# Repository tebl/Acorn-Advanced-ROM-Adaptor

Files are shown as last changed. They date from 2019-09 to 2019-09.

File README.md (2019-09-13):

# Acorn Advanced ROM Adaptor

Recently picked up something called an Advanced ROM MKII Adaptor, a 16K sideways ROM- RAM Adaptor for The Acorn Electron by Advanced Computer Products. The one I have looks like the one below, unfortunately it was had no sockets so both all the ROMs were soldered in and the jumpers used to select the type of chips installed (8K SRAM, 8K ROM or 16K ROM) were nowhere to be seen so not the most exciting piece of kit in my collection. So I decided to recreate the board instead of tearing it down and hacking it to pieces.

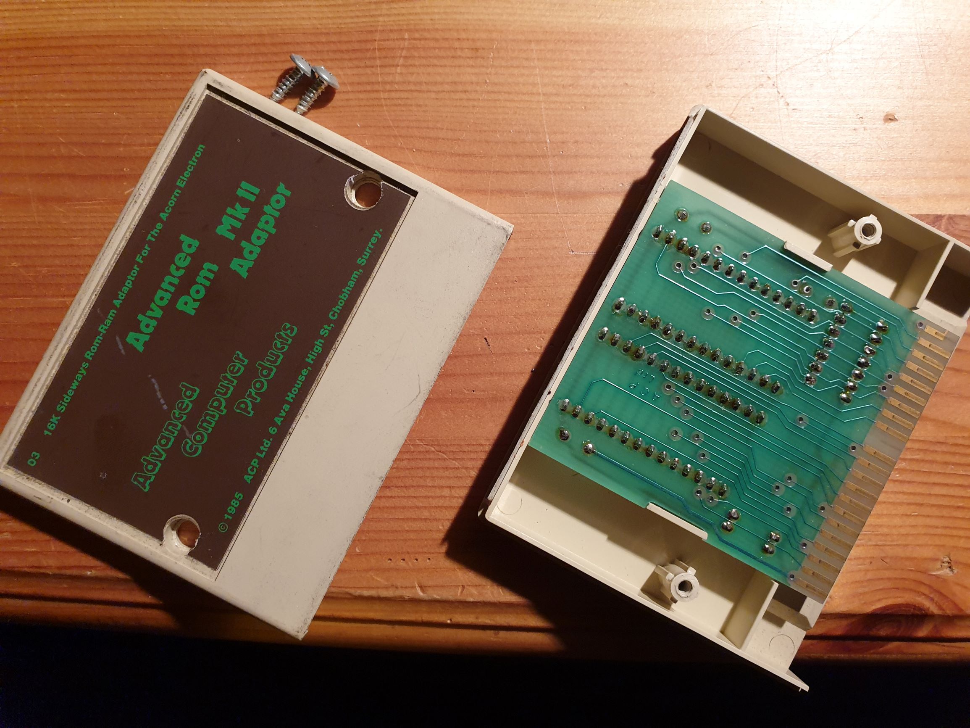
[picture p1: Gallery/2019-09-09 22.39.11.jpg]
MKII ROM Adaptor


The original release of the product had a MKI which only sported a single EPROM, the MKII as already described has the capacity for two chips with the aid of a small piece of added logic. I started by tracing out where every connection went on the MKII, adding up the details into a [schematic](https://github.com/tebl/Acorn-Advanced-ROM-Adaptor/raw/master/MK2%20Original/export/MK2%20Original.pdf) that can be found as part of the project found in*MK2 Original*. I've included them for any that would like to have that kind of information available when attempting to repair a similar cartridge.

Finally I wanted one that I could mess around with, so with the schematic in mind I started drawing out a *MKIII Redux* version of it instead. The differences here is that I've replaced the 27128/27C128, that are a pain to track down and pay for, with the plentiful 27C512 chips instead. This bumps the capacity of the cartridge from 2x16K to 8x16K, addressing is kept the same - the remaining slots are available by changing the jumper settings. 

# Versions
For added details, see following project pages:
- [MKII Original](https://github.com/tebl/Acorn-Advanced-ROM-Adaptor/tree/master/MK2%20Original)
- [MKIII Redux](https://github.com/tebl/Acorn-Advanced-ROM-Adaptor/tree/master/MK3%20Redux)

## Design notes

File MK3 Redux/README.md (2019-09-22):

# Acorn Advanced ROM MKIII Redux

**UNTESTED**

Recently picked up something called an Advanced ROM MKII Adaptor, a 16K sideways ROM- RAM Adaptor for The Acorn Electron by Advanced Computer Products.  I've added a schematic for the MKII as part as the [MKII Original](https://github.com/tebl/Acorn-Advanced-ROM-Adaptor/tree/master/MK2%20Original), this is the *MKIII Redux* and as the name implies it is my attempt to create a cartridge that I can mess around with - without tearing down and hacking up 30 year old irreplaceable hardware.

The differences from the original design is that I've replaced the 27128/27C128, that are a pain to track down and pay for, with the plentiful 27C512. This bumps the capacity of the cartridge from 2x16K to 8x16K though addressing is kept the same, the remaining slots are available by changing the jumper settings with the computer is unplugged. I could have gone for chips that are even larger in capacity, but I wanted something that is easy enough for anyone with a soldering iron to fix up for themselves and there really aren't all that much ROM-based software available so even with the limited 8 slots you'll still fit in most of the desirable titles anyway. Smaller EPROMs such as the 27C64 or 27C256 can still be used, just keep the A14/15 lines unjumpered.

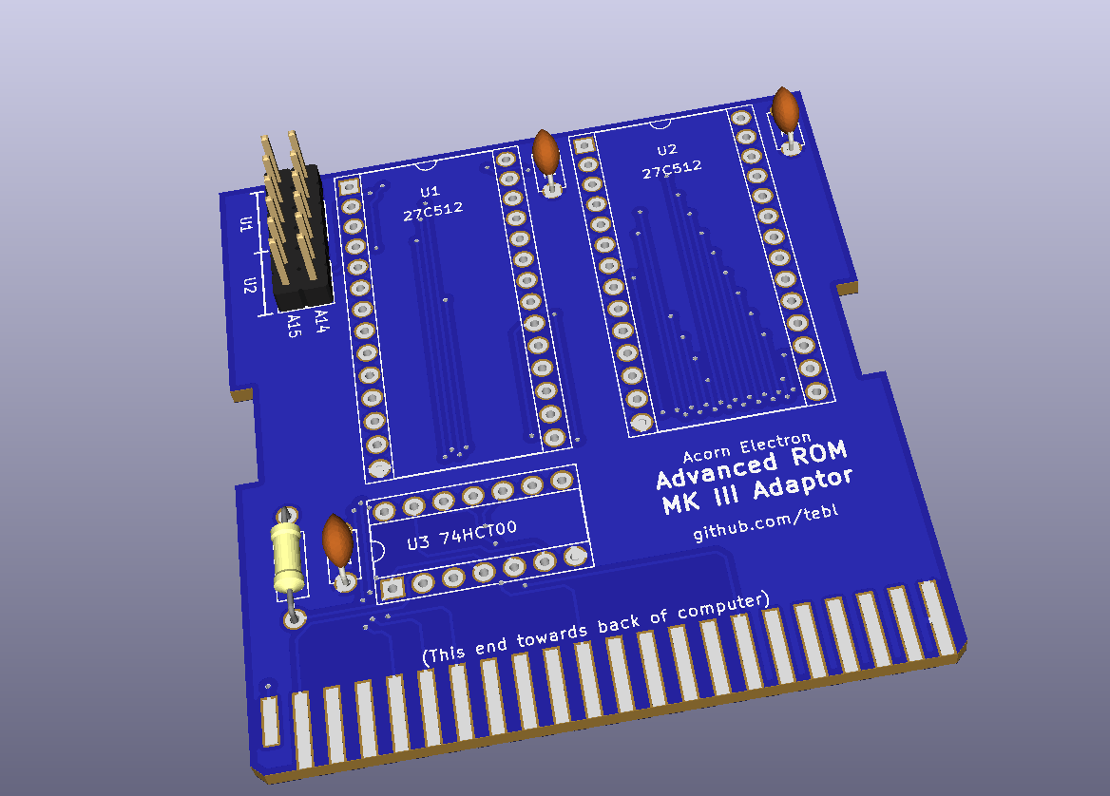
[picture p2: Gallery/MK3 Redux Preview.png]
MKIII Redux PCB Preview


# Schematic
The supplied KiCad files should be sufficient as both a schematic and as a  starting point for ordering PCBs (basically you could just zip the contents of the export folder and upload that on a fabrication site), the schematic is also available in [PDF-format](https://github.com/tebl/Acorn-Advanced-ROM-Adaptor/raw/master/MK3%20Redux/export/MK3%20Redux.pdf) and this is what you'll need to print and work your way through this things don't work as expected after assembly.

# BOM
Most parts should be easy to get a hold of from your favourite local electronic component shop, but given that I don't have access to such shops where I live so everything was based on whatever I could get cheapest from ebay/AliExpress (free shipping, plan on usually waiting 3-4 weeks though). The list below should be everything you'll need in addition to a workable soldering iron and some 60/40 soldering tin. Other tools needed for this project is an EPROM-ereaser as well as an EPROM-programmer for the two ICs (I use MiniPro TL866 for both).

Some vendors will have the same ICs in different form factors, the ones you want will often be specified as being in the form of a DIP/PDIP package. Usually you'll want sockets for each of the ICs as well, a bag of assorted sockets should be easily available without setting you back more than a couple bucks. With the sockets in place, you don't need to dread having to remove an IC later, this leads to easier fault finding and you can even "borrow" them for other projects later! For the pin headers, you probably won't find the exact pin count so just buy the longer versions and snip off the parts you don't need.

| Reference | Item | Count |
| --- | --- | ----- |
| PCB | Fabricate using Gerber files | 1 |
| C1-C3 | 100nF ceramic capacitor | 3 |
| R1 | 10k ohm resistor | 1 |
| U1,U2 | 27C512 DIP-28 | 2 |
| U3 | 74HCT00 DIP-16 | 1 |
| | Male 2x40-pin header (break to size)  | 1 |

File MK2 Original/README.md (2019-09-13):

# Acorn Advanced ROM MKII Original

Recently picked up something called an Advanced ROM MKII Adaptor, a 16K sideways ROM- RAM Adaptor for The Acorn Electron by Advanced Computer Products. The one I have looks like the one below, unfortunately it was had no sockets so both all the ROMs were soldered in and the jumpers used to select the type of chips installed (8K SRAM, 8K ROM or 16K ROM) were nowhere to be seen so not the most exciting piece of kit in my collection. So I decided to redraw the [schematic](https://github.com/tebl/Acorn-Advanced-ROM-Adaptor/raw/master/MK2%20Original/export/MK2%20Original.pdf) for the board, which explains this section of the project, instead of hacking up the cartridge to make it fit my own entertainment purposes.

MKII ROM Adaptor
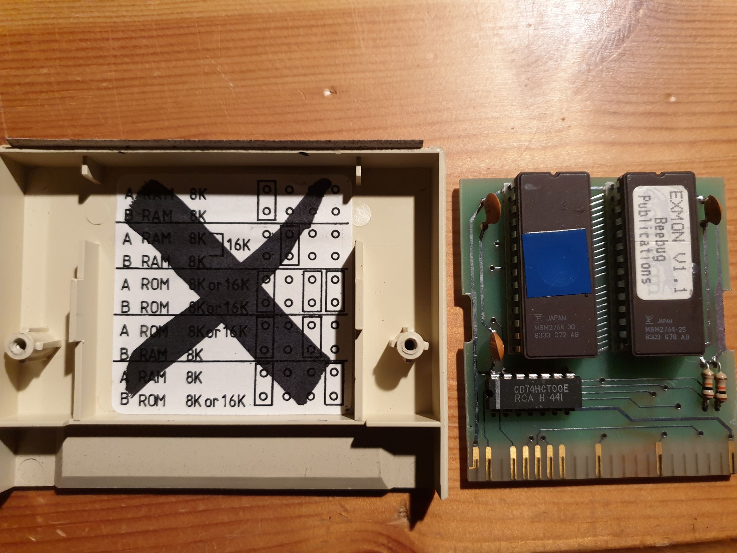
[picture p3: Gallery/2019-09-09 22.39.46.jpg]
MKII Internals


# Schematic
The supplied KiCad files should be sufficient as a schematic, but it is also available in [PDF-format](https://github.com/tebl/Acorn-Advanced-ROM-Adaptor/raw/master/MK2%20Original/export/MK2%20Original.pdf).

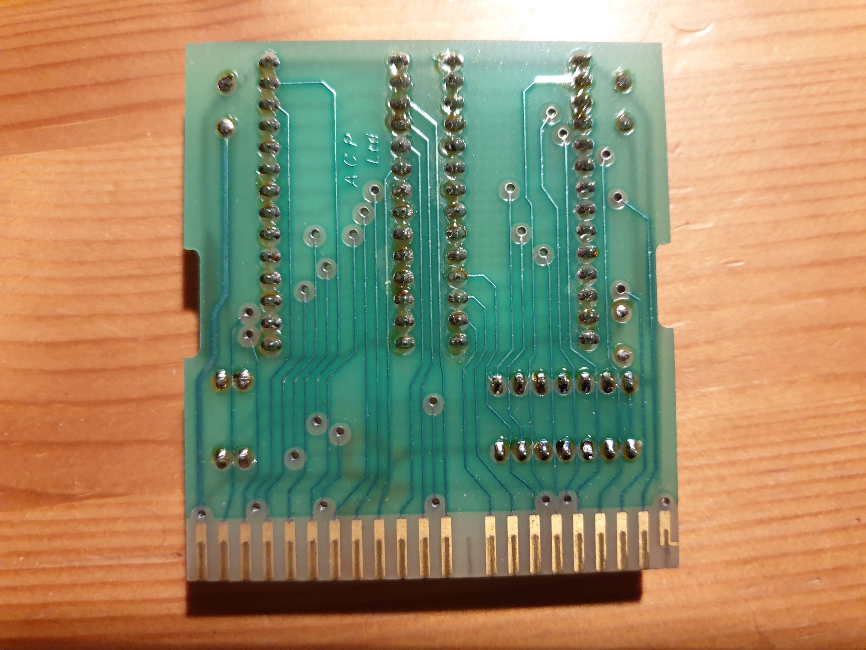
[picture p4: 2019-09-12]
Gallery/2019-09-09 22.41.41.jpg

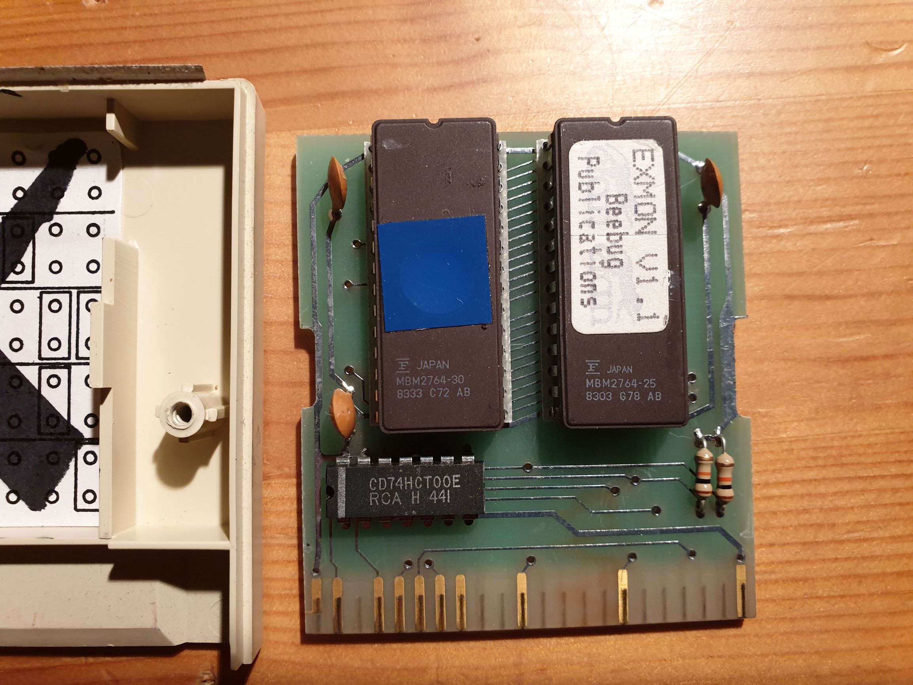
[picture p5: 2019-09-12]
Gallery/2019-09-09 22.41.20.jpg

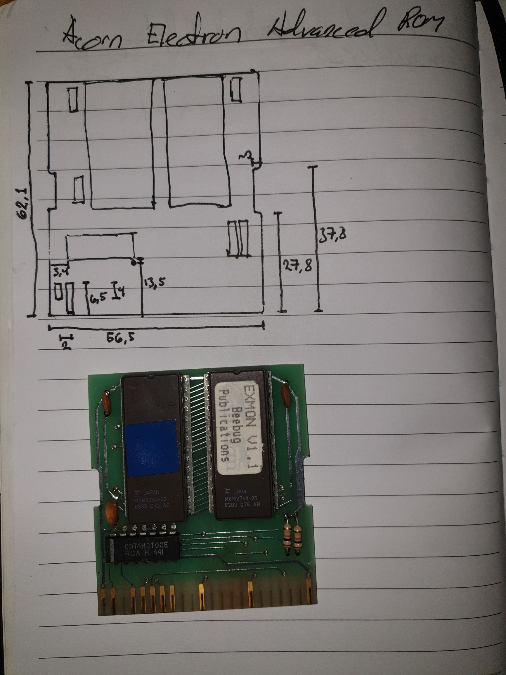
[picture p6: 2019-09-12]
Gallery/2019-09-10 21.29.51.jpg

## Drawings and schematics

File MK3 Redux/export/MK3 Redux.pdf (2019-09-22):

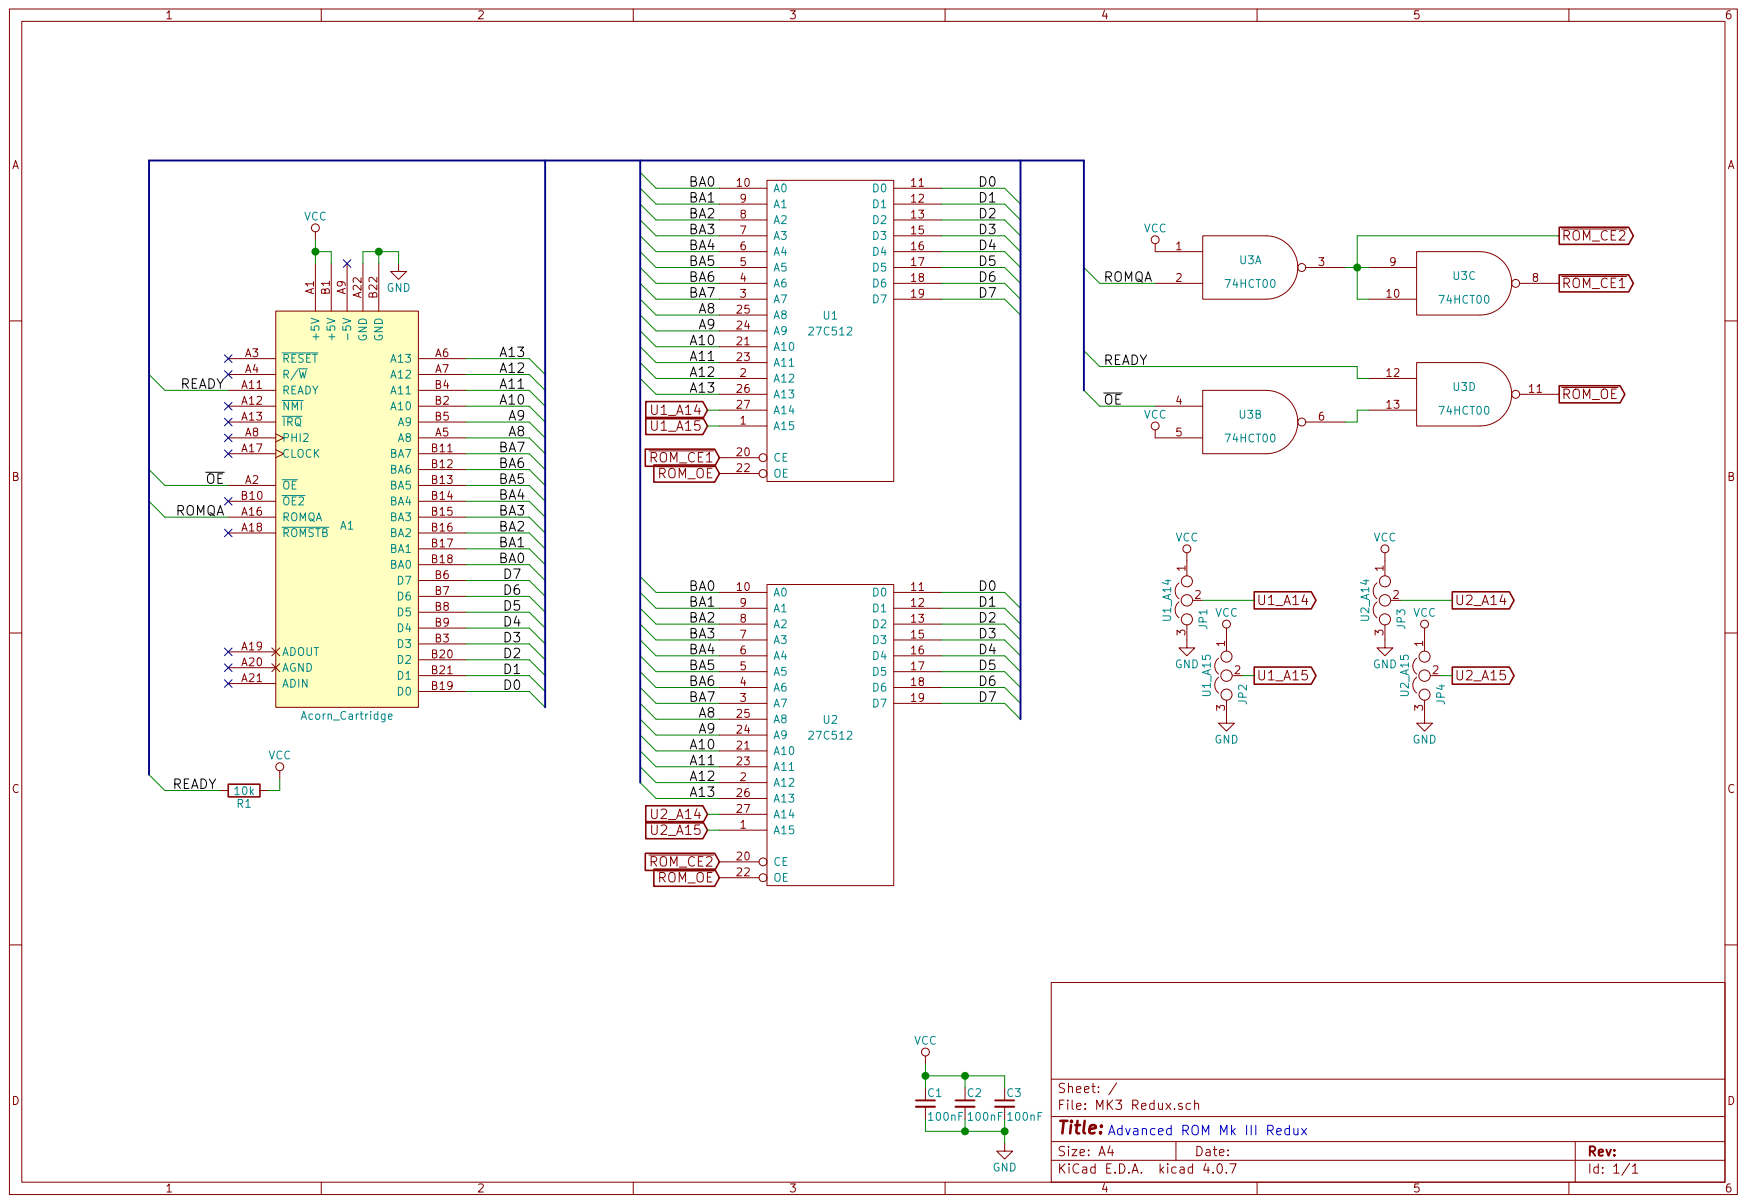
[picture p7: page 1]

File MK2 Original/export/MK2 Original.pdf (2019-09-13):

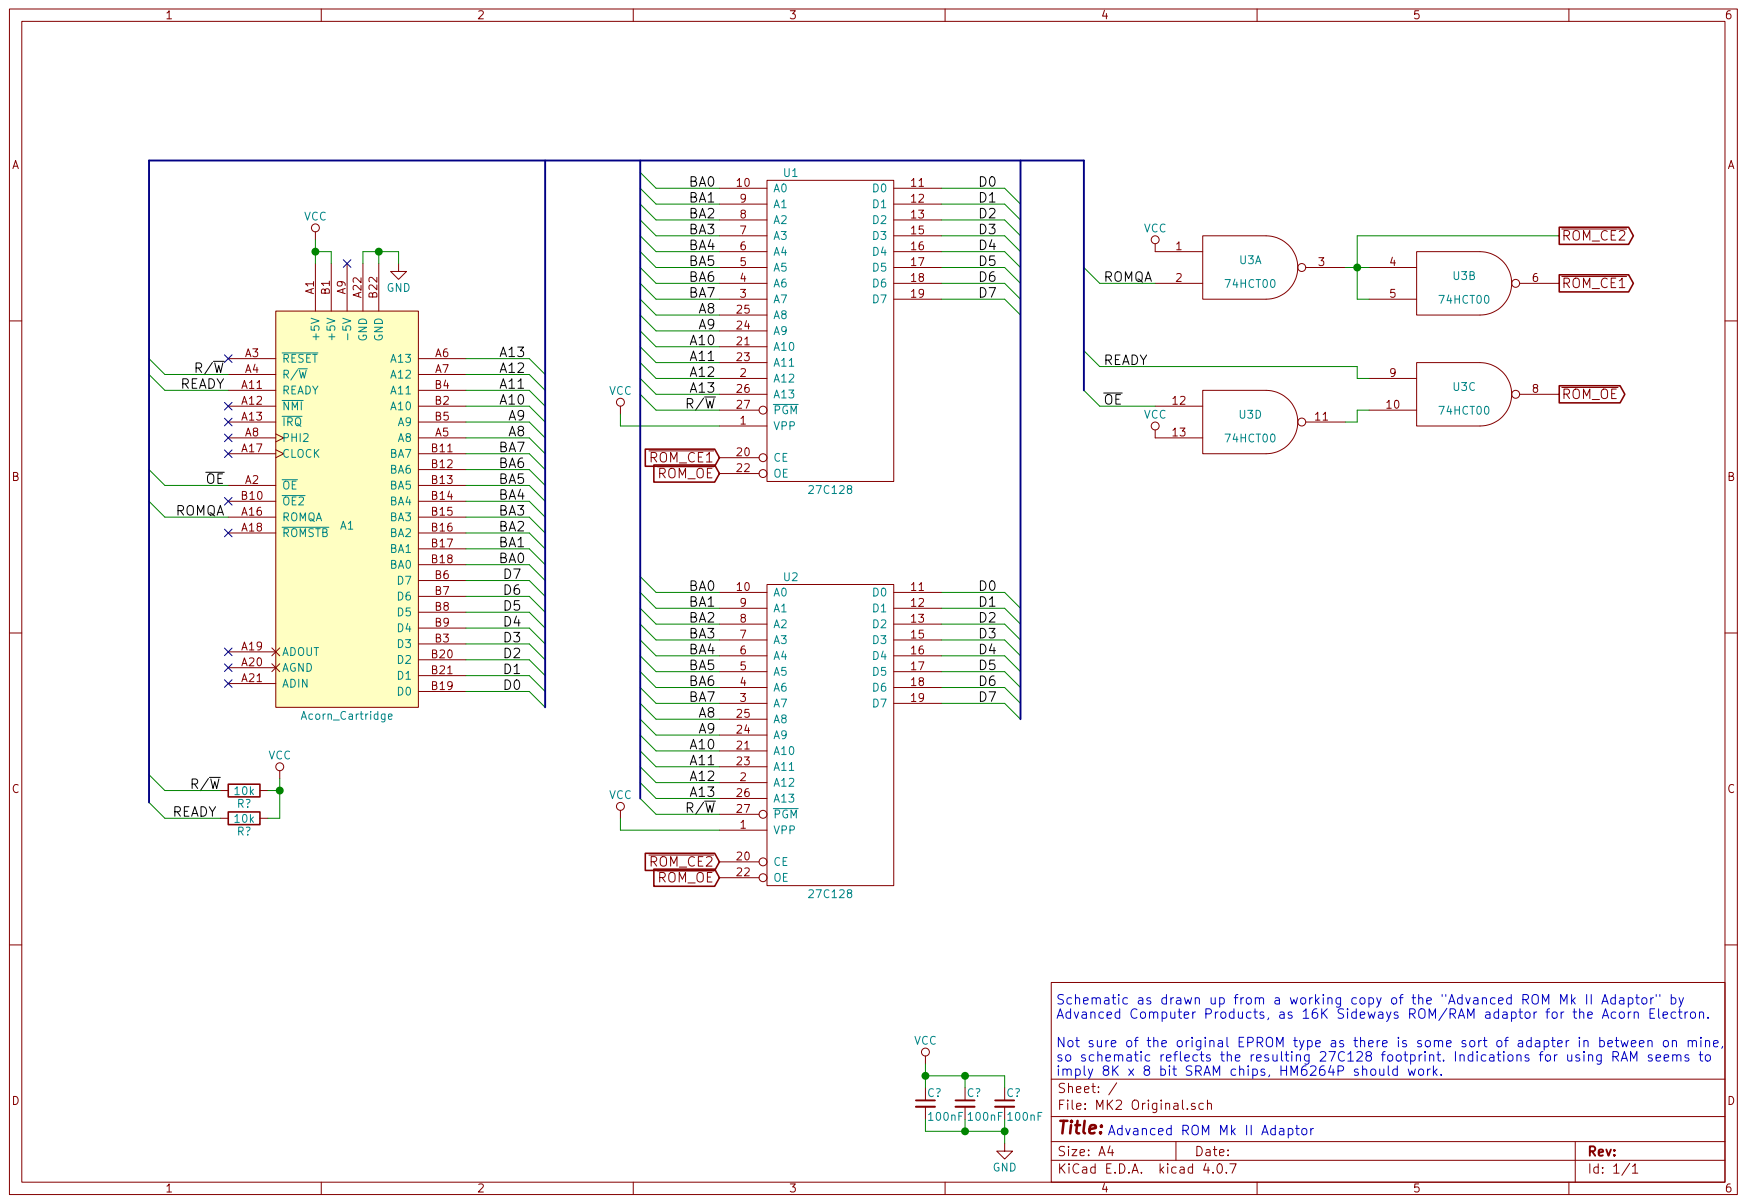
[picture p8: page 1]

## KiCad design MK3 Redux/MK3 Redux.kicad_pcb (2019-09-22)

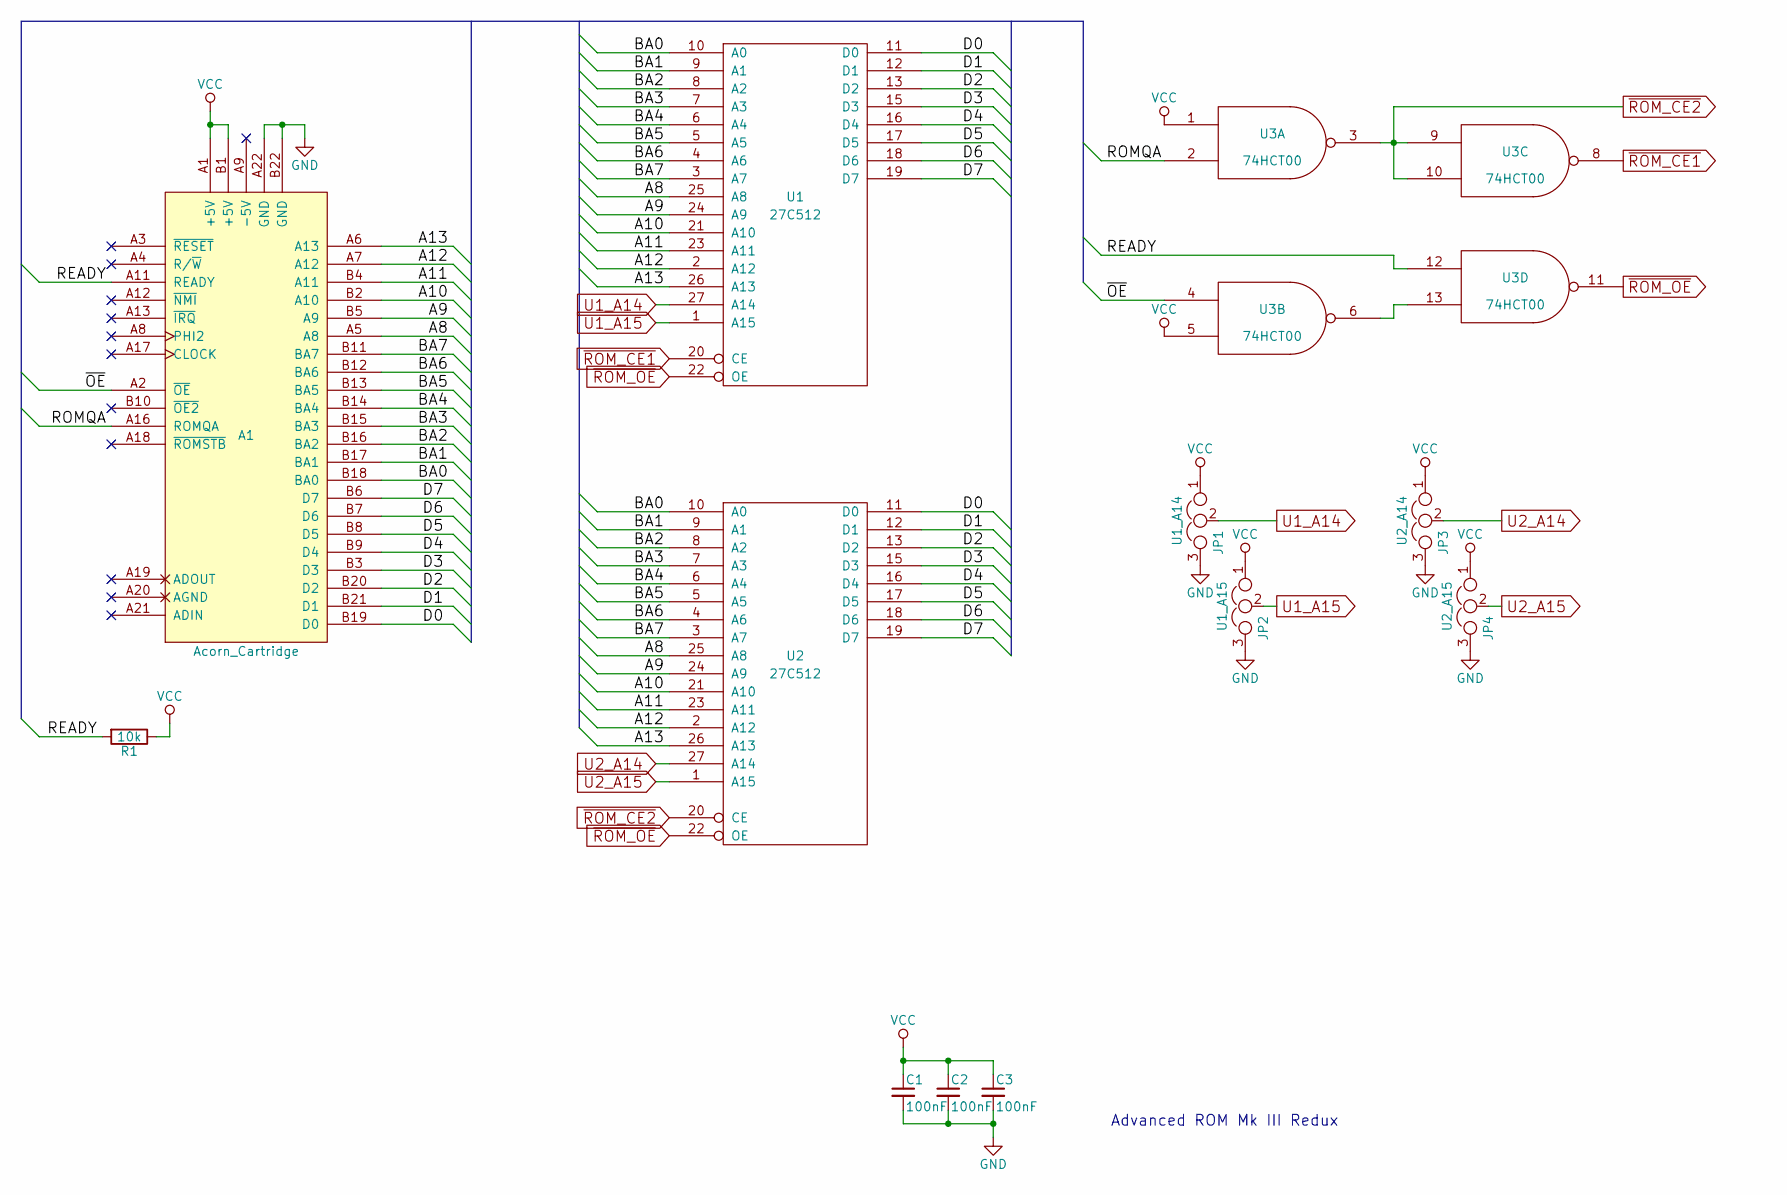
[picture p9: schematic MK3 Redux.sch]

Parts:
A1: Acorn_Cartridge
C1, C2, C3: 100nF; C_Disc_D4.7mm_W2.5mm_P5.00mm
JP1: U1_A14; Pin_Header_Straight_1x03_Pitch2.54mm
JP2: U1_A15; Pin_Header_Straight_1x03_Pitch2.54mm
JP3: U2_A14; Pin_Header_Straight_1x03_Pitch2.54mm
JP4: U2_A15; Pin_Header_Straight_1x03_Pitch2.54mm
R1: 10k; R_Axial_DIN0207_L6.3mm_D2.5mm_P10.16mm_Horizontal
U1, U2: 27C512; DIP-28_W15.24mm_Socket
U3: 74HCT00; DIP-14_W7.62mm_Socket

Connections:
/A8: A1.A5 (A8), U1.25 (A8), U2.25 (A8)
/A9: A1.B5 (A9), U1.24 (A9), U2.24 (A9)
/A10: A1.B2 (A10), U1.21 (A10), U2.21 (A10)
/A11: A1.B4 (A11), U1.23 (A11), U2.23 (A11)
/A12: A1.A7 (A12), U1.2 (A12), U2.2 (A12)
/A13: A1.A6 (A13), U1.26 (A13), U2.26 (A13)
/BA0: A1.B18 (BA0), U1.10 (A0), U2.10 (A0)
/BA1: A1.B17 (BA1), U1.9 (A1), U2.9 (A1)
/BA2: A1.B16 (BA2), U1.8 (A2), U2.8 (A2)
/BA3: A1.B15 (BA3), U1.7 (A3), U2.7 (A3)
/BA4: A1.B14 (BA4), U1.6 (A4), U2.6 (A4)
/BA5: A1.B13 (BA5), U1.5 (A5), U2.5 (A5)
/BA6: A1.B12 (BA6), U1.4 (A6), U2.4 (A6)
/BA7: A1.B11 (BA7), U1.3 (A7), U2.3 (A7)
/D0: A1.B19 (D0), U1.11 (D0), U2.11 (D0)
/D1: A1.B21 (D1), U1.12 (D1), U2.12 (D1)
/D2: A1.B20 (D2), U1.13 (D2), U2.13 (D2)
/D3: A1.B3 (D3), U1.15 (D3), U2.15 (D3)
/D4: A1.B9 (D4), U1.16 (D4), U2.16 (D4)
/D5: A1.B8 (D5), U1.17 (D5), U2.17 (D5)
/D6: A1.B7 (D6), U1.18 (D6), U2.18 (D6)
/D7: A1.B6 (D7), U1.19 (D7), U2.19 (D7)
/READY: A1.A11 (READY), R1.2, U3.12
/ROMQA: A1.A16 (ROMQA), U3.2
/~OE: A1.A2 (~OE), U3.4
GND: A1.A22 (GND), A1.B22 (GND), C1.2, C2.2, C3.2, JP1.3, JP2.3, JP3.3, JP4.3, U1.14 (GND), U2.14 (GND), U3.7 (GND)
unnamed: U3.6, U3.13
U1_A14: JP1.2, U1.27 (A14)
U1_A15: JP2.2, U1.1 (A15)
U2_A14: JP3.2, U2.27 (A14)
U2_A15: JP4.2, U2.1 (A15)
VCC: A1.A1 (+5V), A1.B1 (+5V), C1.1, C2.1, C3.1, JP1.1, JP2.1, JP3.1, JP4.1, R1.1, U1.28 (VCC), U2.28 (VCC), U3.1, U3.5, U3.14 (VCC)
~ROM_CE1: U1.20 (CE), U3.8
~ROM_CE2: U2.20 (CE), U3.3, U3.9, U3.10
~ROM_OE: U1.22 (OE), U2.22 (OE), U3.11

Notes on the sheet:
Advanced ROM Mk III Redux

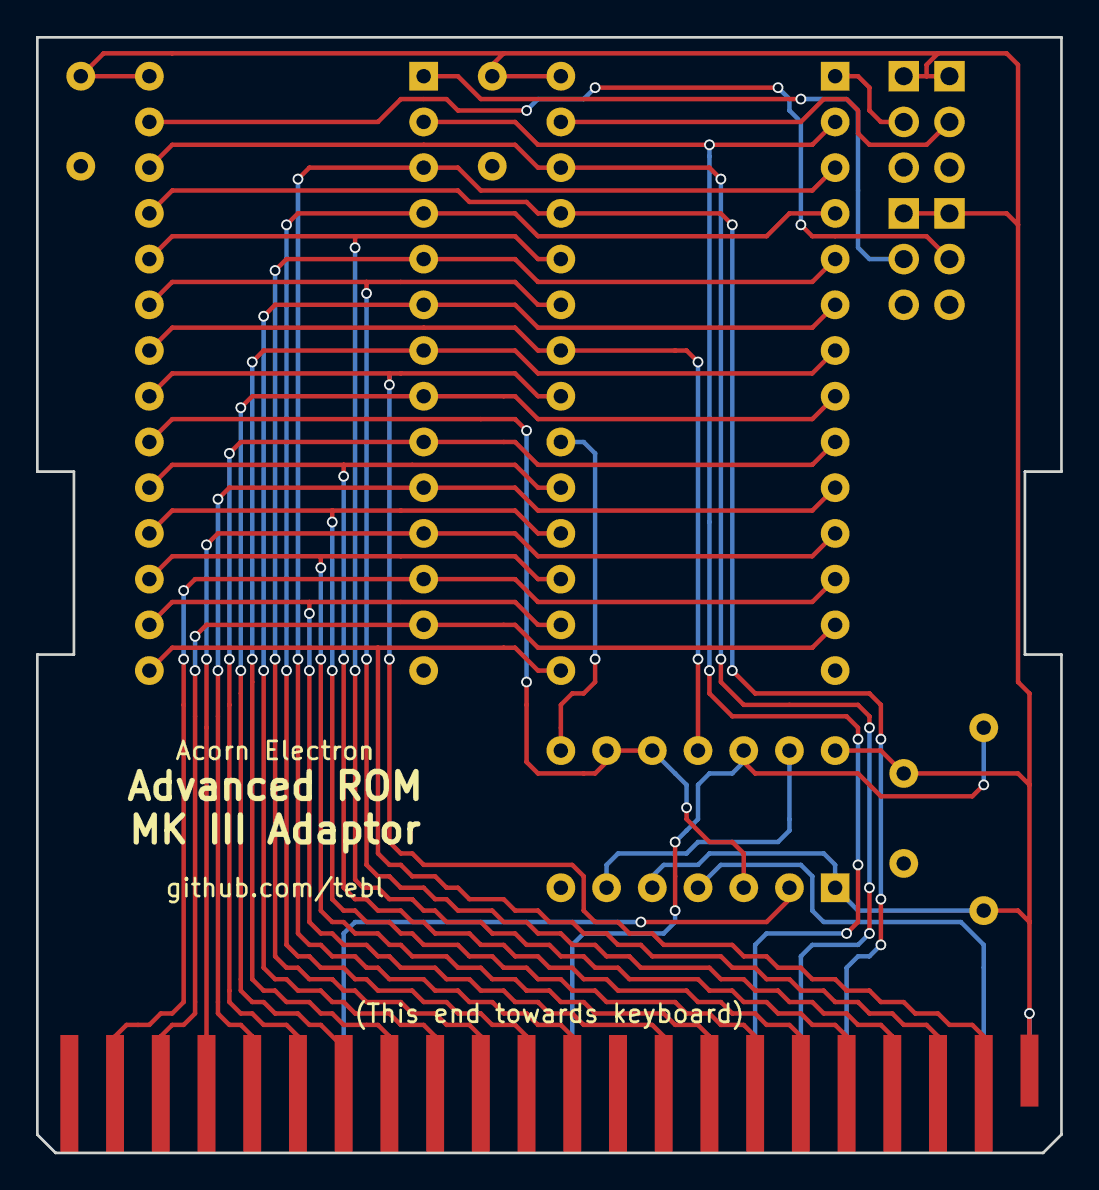
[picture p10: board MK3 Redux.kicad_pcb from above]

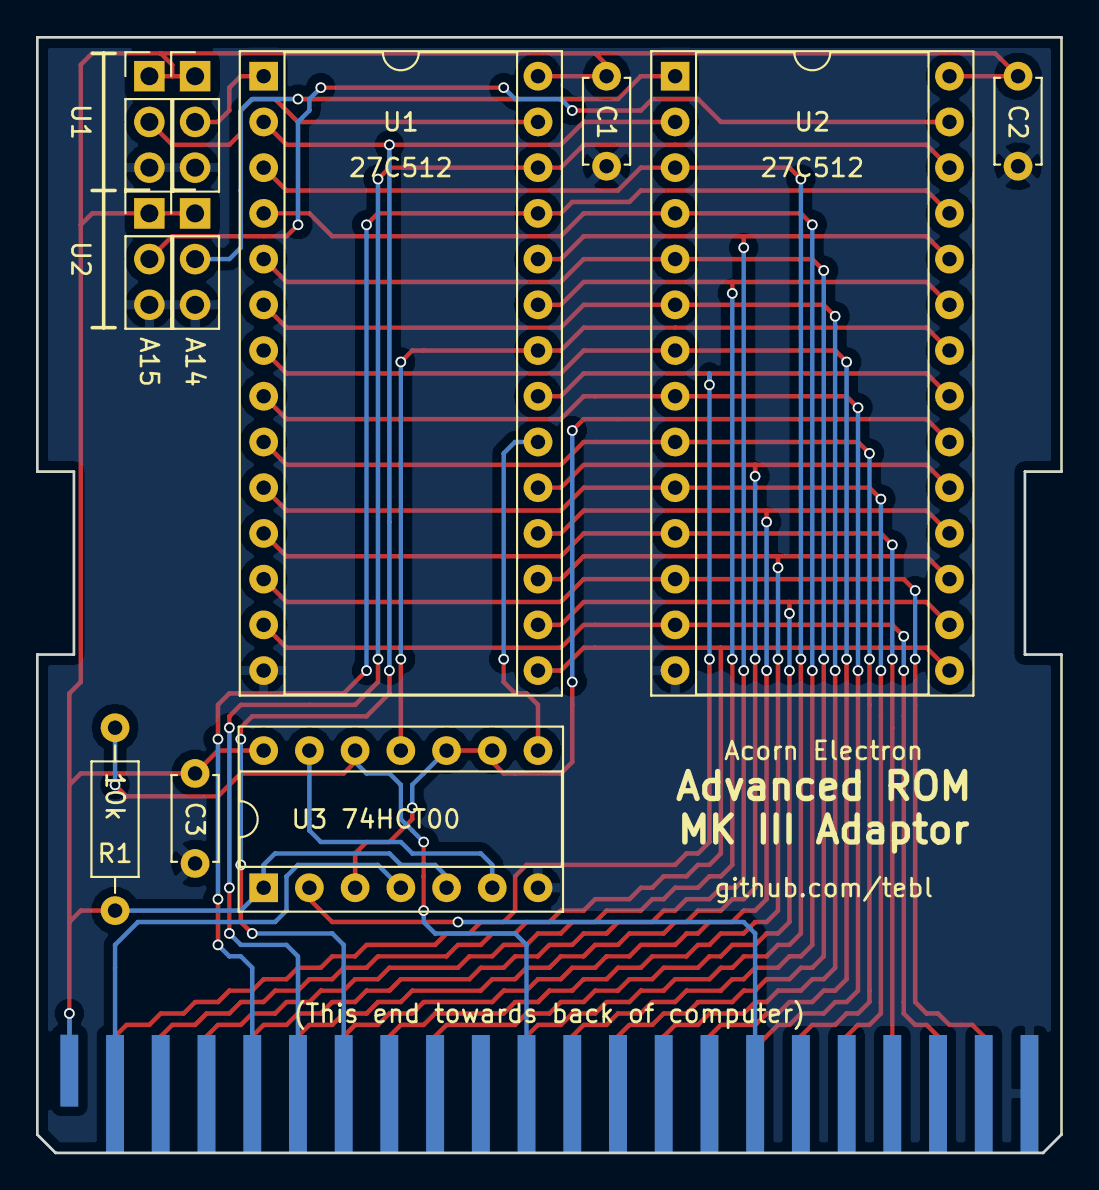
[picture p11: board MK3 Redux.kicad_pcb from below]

Board: 2 copper layers, 56.9 x 62.0 mm, 12 parts (11 on the bottom side), 35 nets.

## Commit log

2019-09-12 MK2 schematic recreated
    [MK2 Original.kicad_pcb, MK2 Original.sch]
2019-09-12 Created MK3 Redux board
    [MK3 Redux.kicad_pcb, MK3 Redux.sch]
2019-09-13 Added schematic pdf
2019-09-13 Gerber export
    [MK3 Redux-B.Cu.gbl, MK3 Redux-B.Mask.gbs, MK3 Redux-B.Paste.gbp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]
